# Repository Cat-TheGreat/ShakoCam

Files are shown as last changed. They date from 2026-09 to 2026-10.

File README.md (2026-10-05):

 # ShakoCam
An athletic headband with a camera. Like a GoPro, but sleeker, smaller, and much more comfortable and affordable. Designed to take POV videos during marching band performances, which is where the name comes from. My band director once said that you never really know what actually happened at the last competition of the season because the only evidence is memories, and memories tend to shift. That line was most of the inspiration for this project, and I hope it can solve the eternal dilemma.
 ## How It Works
A 1000mAh battery powers a Xiao ESP32S3, chosen for its small size but big processing power. The ESP32S3 runs its own WiFi network, which the user can connect to on their phone. They then open up a web app on their browser, which allows the user to Start/Stop recording, view SD card storage, and view recorded videos in the browser, as well as download them as MP4s to their phone. The video is recorded through an OV3660 with a 120 degree lens to capture the user's field of view. The battery can be recharged using the ESP32S3's USB. 
 ## How To Build It
 ### 1. Prepping Electronics
Follow this wiring diagram to solder the 26 AWG wire from the LiPo battery to the ESP32S3
Wires_Connections V1

Locate the camera module that comes with the ESP32S3, flip the black latch open, and remove it. Insert the longer OV3660 module.
Upload ShakoCam code onto the ESP32S3, make sure you can access the web app with your phone by connecting to ShakoCam WiFi and opening http://192.168.4.1/
 ### 2. Enclose the Electronics
3D print the battery, camera module, and ESP32S3 cases. Onshape: https://cad.onshape.com/documents/f96a4d49e3e12c14028028a5/w/6497ad0440bc11f84819475d/e/ab09dfae09777d82fe9ced0d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
Place Velcro as shown
Velcro V1

Carefully put components in their respective enclosure and make sure all pieces are secured
 ### 3. Mounting onto the headband
Cut the outer layer of the inside of the headband to get access to the inner layers
Sew matching velcro pieces onto the inside of the headband 
Attach the ESP32S3 and battery cases
Cut a hole where you want the camera lens to be, then put the camera module enclosure through and secure loose threads with adhesive
Enjoy your ShakoCam! Final product should look like this: CAD V1 Bird's View
CAD V1 Back Tilt
CAD V1 Front Tilt

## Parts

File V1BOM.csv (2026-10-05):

Item Name | Estimated Cost | Link | Total Cost
Xiao ESP32S3 Sense | $13.99 | https://www.seeedstudio.com/XIAO-ESP32S3-Sense-p-5639.html | $35.66
1000mAh 503450 LiPo Battery 3.7V | $6.41 | https://www.aliexpress.us/item/3256812637605261.html?curPageLogUid=JEKEjuLBBcFY
OV3660 Camera Module | $8.02 | https://www.aliexpress.us/item/3256812309268272.html?curPageLogUid=TWeHf9uH6LLx
26 AWG Wires | $2.26 | https://www.aliexpress.us/item/3256801954164415.html?curPageLogUid=quLryT4fYQDY
3D Printed Parts | $2.50
Black Velcro | $1.90 | https://www.aliexpress.us/item/3256805406910291.html?curPageLogUid=CvVZhRHr8c55
Black Headband | $0.58 | https://www.aliexpress.us/item/3256803432347899.html?curPageLogUid=vUSZnRrO4lS8

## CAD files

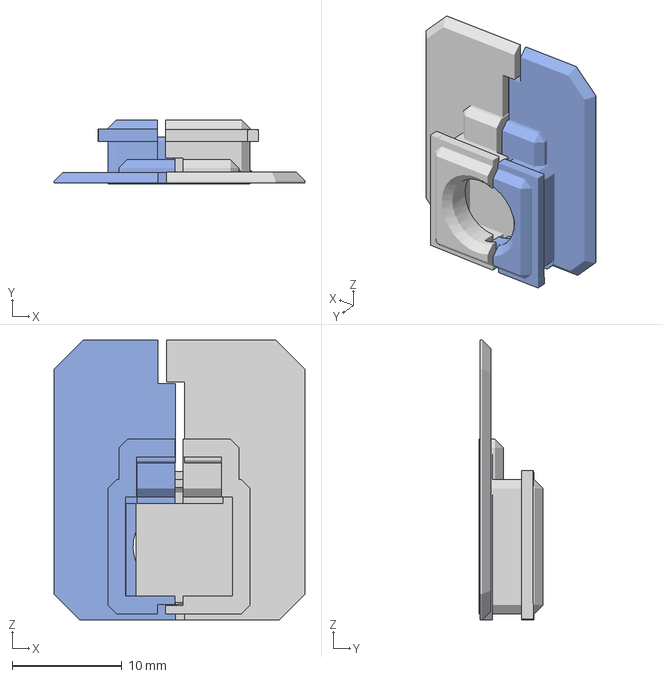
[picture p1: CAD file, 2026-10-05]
CAD/Camera Module CaseV1.step
22.8 x 5.86 x 25.5 mm

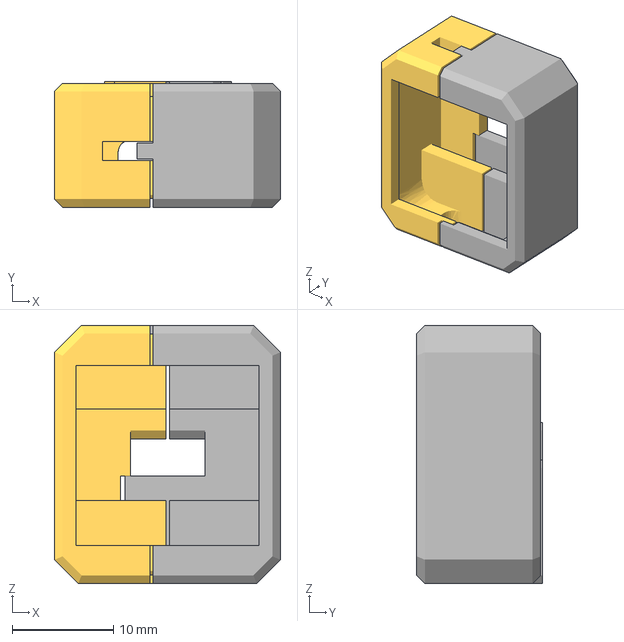
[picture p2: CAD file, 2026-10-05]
CAD/ESP32S3 Case V1.step
22.3 x 12.4 x 25.5 mm

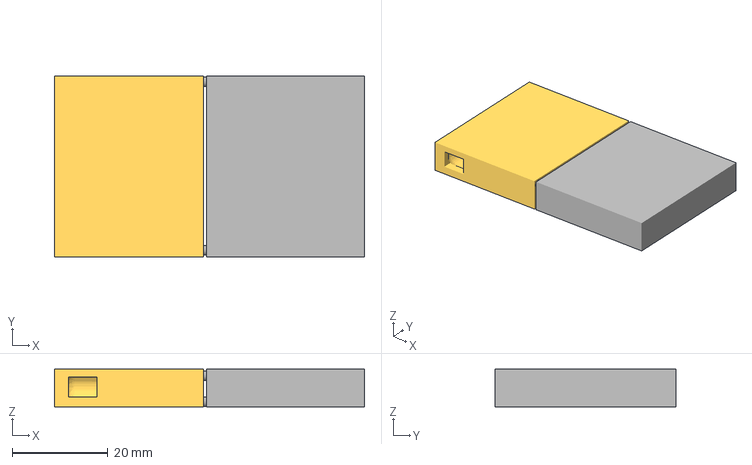
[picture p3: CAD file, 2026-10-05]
CAD/Battery Case V1.step
64.6 x 37.7 x 7.92 mm

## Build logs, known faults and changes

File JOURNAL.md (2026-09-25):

6/28/2026-Made the first initial sketch for ShakoCam, a headband with electronics concealed within it that records audio and video.
7/07/2026-After doing some research about the components, I made a list of all the components it would take for the first prototype, decided on using XIAO ESP323 and a 500mAh LiPo battery
7/21/2026-Got the first ever photo and video on my ESP32S3, used a 32GB Class 4 SanDisk microSD card that was laying around. However, the video was just one frame, so I tried to use ESP32-CAM_MJPEG2SD to actually get a proper avi recorder not like the one in the examples. Even after trying some other open source projects, they would just not work.
7/23/2026-Found another project to get a recorder up and running, but I could not succesfully convert it from ESP32 to ESP32S3(probably the Windows 7 lol), even with AI help. I switched to a different version of the same project and tried to modify that under the guidance of ChatGPT.
7/24/2026-Journaled "it feels like I'm going around in circles", used Arduino AI which did not help, after using so much AI it messed up the code, so I asked Gemini to simply write its own code from scratch. Unlike my past attempts, it successfully connected to the SD card but was having issues with taking frames. I went back to the previous code I was working on and got it to advance to a spinlock error. It was still having Sd card issues so I tried switching it from Sd_MMC to SPI but that still did not work.
7/26/2026-Still fixing the spinlock error
7/28/2026-Got frustrated with the spinlock error and simply tried using an older version of MJPEG2SD, also did not work.
7/29/2026-Once again returned to the code with the spinlock error and after switching some things around the Serial Monitor was glitching so I got frustrated and redirected my focus to the audio rather than the video. Used the SEEED Studio example to get it to record audio, and then modified it so it would start recording when it received power. Used my 5000mAh power bank to prototype and record audio. I put the whole setup in a hastily made cardboard enclosure and took it to rehearsal to see how it would withstand loud sounds.
7/30/2026-Was not able to get a recording of the band playing loud :( but it recorded the director's motivational speech just fine, however set volume gain to 0 in preparation
8/01/2026-Breakthrough Day! Feeling down since the recorder didn't even activate during rehearsal, so I went and tried getting the simplest possible video recorder going. This is when I dug around in the files of the first ever video I took, the single frame one, and found that the project I used had a folder called a decoder. Thus I did some research and through freeconverter.com I turned the one frame video into a multiple frame video! So I discovered I could just take the really simple example video recorder and put that file through a decoder and get real video. So with the help of Gemini I made a WebApp for it since the ESP32S3 has a wifi network, and I got it to control the LED with my phone which was so cool. Then, I got it to be able to press a button to my phone and save a .txt file to the SD card. Finally, I got Gemini to merge the very simple video code with the web app code to create a web app that stopped and started recording from my phone. Then, added a gallery so you can select videos and view them using the web app's decoder. Very proud.
8/02/2026-I deleted the code from the previous day by accident :( but somehow got it back? and then I worked on adding a download as .mp4 button and making it able to switch from one video, and then clicking on another video. I also tried improving the load time of the video viewer because that took a while. Successfully added the download button,also a visual to see how much storage you have left, and then I pivoted to adding audio. It did not go so well, I even accidentally deleted HandleStream in the code. I got a clip with "MEGA glitchy" audio, and in trying to fix that I broke the video recording somehow.
8/03/2026-I commented out the microphone code and the video code was back and running :), decided that the best course of action was to record a .avi and .wav simultaneously and then combine them in the web app. After hacking away at it, I got 7 seconds of crappy audio for 38 seconds of video, however my speech was audible. I added a mutex-not sure for what? Using a stopwatch I timed the length of the video, turns out it was playing way too slow for the frames it took. Using the combined powers of ChatGPT and Gemini a clock was implemented to sync them, which somehow cleared up the audio quality as well. It worked like a camera which I was very proud of. However this broke the download button because codec was not read, I got it to download but my phone displayed that it was 6 seconds long but it played the 1min and 16sec long video which was odd.
8/04/2026-Big Mistake Day: We were doing a part of our show that we had never done before and I really wanted to film it, and I thought with all this progress that it was ready, so I tried putting the battery pack and the ESP32S3 onto a baseball cap. This concluded in me using a tic tac box to house the ESP32S3. Bad mistake. I think this broke the ribbon cable, which broke the camera module. It was not able to record video after this :(
8/05/2026-Trying to confirm that the camera module was broken, I somehow corrupted the SD card and spent my time researching how to and recovering the SD card.
8/06/2026-Did not successfully recover the videos, but even after plugging in the fresh SD card the camera still couldn't even take simple photos it was just all black, so I reached out to customer support to see if they would replace it.
8/16/2026-Customer support did in fact send a replacement ESP32S3 yay! So learning from my mistakes I measured the dimensions of the ESP32S3 and designed a blocky enclosure in TinkerCad
8/26/2026-The replacement ESP32S3 arrived from Seeed on this day
8/29/2026-After unboxing the XIAO I plugged into the beautiful Windows 7 and it said it was printer. So, I plug in the old one and it says it is also a printer. Wow! I messed around for a bit with the drivers and I got Arduino to recognize it. I sent my expertly designed case to the school library to get printed, and got notified that the 3d printer was broken. I got the new ESP32S3 to run CameraWebServer! In a tragic turn of events, I tried disconnecting the Wifi antennae and accidentally took the whole connector with it so I discreetly swapped boards with the old one. CameraWebServer executed perfectly and when I upload the ShakoCam code and test the audio while I play my instrument the audio pops. Therefore, I lower volume gain and adjust the clock speed.
9/07/2026-On this day I realize I can just get a masterfully designed case from the internet instead of designing it myself. I send this to the library. I begin contemplating the battery because that's the bulkiest part at this point.
9/14/2026-I finally get the 3d print! I take out all the supports and it fits perfectly. However, is it a lot bulkier than I imagined and might not sleekly go into a headband. I also ordered a 1000mAh LiPo battery which might be a little overkill but better safe than sorry. With the case, I can now start testing.
9/16/2026-I put the power bank and the ESP32S3 in my fanny pack and take it out the rehearsal! It survived the ruthless heat and loud conversations, although I couldn't connect it fast enough to get a video of the band actually playing. I made a note that the video is really low quality.
9/17/2026-I get some really good videos 20-30 min long of our rehearsal, the first time I record our whole band. However the camera was aimed at the inside of the fanny pack and I did not get to analyze the videos much because I was busy, but it handled itself pretty well + had some mic popping and timing issues here and there 
9/25/2026-Tragedy strikes. It's been a week since the fanny pack was lost, with all the components in it :(. I research funding options to replace all that I have lost because I've spent a lot already, and I found HackClub. I started this GitHub repository and paraphrased everything from my journal. Also, someone between this and 9/17 I took apart an old Joy-Con to see if any parts could be salvaged and I realized how big soldering will be in this project, which I have 0 experience with. I also confirmed that the old ESP32S3 still works, just doesn't have an SD card or a functioning camera module.

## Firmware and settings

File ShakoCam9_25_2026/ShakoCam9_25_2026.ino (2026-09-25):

#include "esp_camera.h"
#include "FS.h"
#include "SD.h"
#include "SPI.h"
#include "esp_timer.h"
#include <WiFi.h>
#include <WebServer.h>
#include "driver/i2s.h"

// Microphone Pin & Channel Definitions
#define I2S_MIC_CLK     42
#define I2S_MIC_DATA    41
#define SAMPLE_RATE     16000U
#define SAMPLE_BITS     16

#define CAMERA_MODEL_XIAO_ESP32S3
#include "camera_pins.h"

const char* ssid = "ShakoCam";
const char* password = "password123";
WebServer server(80);

SemaphoreHandle_t sdMutex;
TaskHandle_t audioTaskHandle = NULL;

const int SD_PIN_CS = 21;

// Separate File Handles for Video and Audio
File videoFile;
File audioFile;

bool camera_sign = false;
bool sd_sign = false;
volatile bool isRecording = false;

char currentFilename[32];  // e.g. /video0.avi
char audioFilename[32];    // e.g. /audio0.wav

int frameCount = 0;
uint32_t audioBytesWritten = 0;

// Helper function to write a standard 44-byte WAV Header
void writeWavHeader(File file, uint32_t sampleRate, uint16_t bitsPerSample, uint16_t channels) {
  uint8_t header[44];
  
  // "RIFF" chunk descriptor
  header[0] = 'R'; header[1] = 'I'; header[2] = 'F'; header[3] = 'F';
  uint32_t fileSize = 0; // Temporary placeholder
  memcpy(&header[4], &fileSize, 4);
  header[8] = 'W'; header[9] = 'A'; header[10] = 'V'; header[11] = 'E';

  // "fmt " sub-chunk
  header[12] = 'f'; header[13] = 'm'; header[14] = 't'; header[15] = ' ';
  uint32_t subchunk1Size = 16; // PCM format
  memcpy(&header[16], &subchunk1Size, 4);
  uint16_t audioFormat = 1;   // Uncompressed PCM
  memcpy(&header[20], &audioFormat, 2);
  memcpy(&header[22], &channels, 2);
  memcpy(&header[24], &sampleRate, 4);
  
  uint32_t byteRate = sampleRate * channels * (bitsPerSample / 8);
  memcpy(&header[28], &byteRate, 4);
  uint16_t blockAlign = channels * (bitsPerSample / 8);
  memcpy(&header[32], &blockAlign, 2);
  memcpy(&header[34], &bitsPerSample, 2);

  // "data" sub-chunk
  header[36] = 'd'; header[37] = 'a'; header[38] = 't'; header[39] = 'a';
  uint32_t dataSize = 0; // Temporary placeholder
  memcpy(&header[40], &dataSize, 4);

  file.write(header, 44);
}

void initMicrophone() {
  i2s_config_t i2s_config = {
    .mode = (i2s_mode_t)(I2S_MODE_MASTER | I2S_MODE_RX | I2S_MODE_PDM),
    .sample_rate = 16000,
    .bits_per_sample = I2S_BITS_PER_SAMPLE_16BIT,
    .channel_format = I2S_CHANNEL_FMT_ONLY_LEFT,
    .communication_format = I2S_COMM_FORMAT_STAND_I2S,
    .intr_alloc_flags = ESP_INTR_FLAG_LEVEL1,
    .dma_buf_count = 4,
    .dma_buf_len = 512,
    .use_apll = false,
    .tx_desc_auto_clear = false,
    .fixed_mclk = 0
  };

  i2s_pin_config_t pin_config = {
    .bck_io_num = I2S_PIN_NO_CHANGE,
    .ws_io_num = I2S_MIC_CLK,
    .data_out_num = I2S_PIN_NO_CHANGE,
    .data_in_num = I2S_MIC_DATA
  };

  esp_err_t err = i2s_driver_install(I2S_NUM_0, &i2s_config, 0, NULL);
  if (err != ESP_OK) {
    Serial.printf("I2S driver install failed: %d\n", err);
    return;
  }

  err = i2s_set_pin(I2S_NUM_0, &pin_config);
  if (err != ESP_OK) {
    Serial.printf("I2S pin setup failed: %d\n", err);
    return;
  }

  i2s_start(I2S_NUM_0);
  Serial.println("Lightweight PDM Microphone Initialized!");
}

const char INDEX_HTML[] PROGMEM = R"rawliteral(
<!DOCTYPE html>
<html>
<head>
  <meta name="viewport" content="width=device-width, initial-scale=1">
  <style>
    body { font-family: Arial, sans-serif; text-align: center; background: #121212; color: white; padding: 15px; margin: 0; }
    .btn { padding: 12px 24px; font-size: 16px; border: none; border-radius: 8px; margin: 5px; cursor: pointer; font-weight: bold; }
    .rec { background-color: #e50914; color: white; }
    .stop { background-color: #555555; color: white; }
    .save { background-color: #28a745; color: white; width: 100%; max-width: 320px; }
    .refresh { background-color: #007aff; color: white; padding: 6px 12px; font-size: 14px; border-radius: 5px; border: none; }
    #status { margin: 10px; font-size: 15px; color: #00ffcc; }
    
    #storageBox { background: #1e1e1e; padding: 12px; border-radius: 8px; margin: 15px auto; max-width: 400px; text-align: left; }
    .bar-bg { background: #333; height: 12px; border-radius: 6px; overflow: hidden; margin-top: 6px; }
    .bar-fill { background: #00ffcc; height: 100%; width: 0%; transition: width 0.4s ease; }

    #playerContainer { display: none; margin: 15px auto; max-width: 400px; background: #1e1e1e; padding: 15px; border-radius: 10px; }
    #canvasDisplay { width: 100%; height: auto; border-radius: 6px; background: #000; }
    
    #gallery { margin-top: 20px; text-align: left; background: #1e1e1e; padding: 15px; border-radius: 10px; max-width: 400px; margin-left: auto; margin-right: auto; }
    .file-item { display: flex; justify-content: space-between; align-items: center; padding: 10px 0; border-bottom: 1px solid #333; }
    .file-info { display: flex; flex-direction: column; }
    .file-meta { font-size: 12px; color: #aaa; margin-top: 3px; }
    .play-btn { background: #007aff; color: white; border: none; padding: 8px 12px; border-radius: 6px; cursor: pointer; font-weight: bold; }
  </style>
</head>
<body>
  <h2>ShakoCam</h2>
  <button class="btn rec" onclick="startRec()">RECORD</button>
  <button class="btn stop" onclick="stopRec()">STOP</button>
  <div id="status">Status: Ready</div>

  <div id="storageBox">
    <div style="display:flex; justify-content:space-between; font-size:13px;">
      <span>SD Card Storage</span>
      <span id="storageText">Loading...</span>
    </div>
    <div class="bar-bg">
      <div id="storageBar" class="bar-fill"></div>
    </div>
  </div>

  <div id="playerContainer">
    <h4 id="nowPlaying" style="margin: 5px 0 10px 0;">Video Player</h4>
    <canvas id="canvasDisplay"></canvas>
    <audio id="audioPlayer" controls style="width: 100%; margin-top: 10px; display: none;"></audio>
    <br><br>
    <button class="btn save" id="dlBtn" onclick="saveAsMP4()">Save to Phone</button>
  </div>

  <div id="gallery">
    <div style="display: flex; justify-content: space-between; align-items: center;">
      <h3 style="margin:0;">Saved Clips</h3>
      <button class="refresh" onclick="loadGallery()">Refresh</button>
    </div>
    <div id="fileList" style="margin-top: 10px;">Loading files...</div>
  </div>

  <script>
    let playAnimationId = null;
    let extractedFrames = [];
    let isPlaying = false;
    let activeFilename = "";

    function startRec() {
      fetch('/start');
      document.getElementById('status').innerText = "Status: Recording Video & Audio...";
    }
    
    function stopRec() {
      fetch('/stop');
      document.getElementById('status').innerText = "Status: Stopped & Saved!";
      setTimeout(() => { loadGallery(); loadStorage(); }, 1000);
    }
    
    function loadStorage() {
      fetch('/storage').then(r => r.json()).then(data => {
        const freeMB = data.total - data.used;
        const usedPct = ((data.used / data.total) * 100).toFixed(1);
        document.getElementById('storageText').innerText = (freeMB/1024).toFixed(1) + " GB free of " + (data.total/1024).toFixed(1) + " GB";
        document.getElementById('storageBar').style.width = usedPct + '%';
      }).catch(err => {
        document.getElementById('storageText').innerText = "Unavailable";
      });
    }

    function loadGallery() {
      fetch('/list')
        .then(r => r.json())
        .then(files => {
          let html = '';
          if (!files || files.length === 0) {
            html = '<p>No recordings found.</p>';
          } else {
            files.forEach(f => {
              const sizeMB = (f.size / (1024 * 1024)).toFixed(1);
              html += '<div class="file-item">' +
                '<div class="file-info">' +
                  '<strong>' + f.name + '</strong>' +
                  '<span class="file-meta">Size: ' + sizeMB + ' MB</span>' +
                '</div>' +
                '<button class="play-btn" onclick="playVideo(\'' + f.name + '\')">PLAY</button>' +
              '</div>';
            });
          }
          document.getElementById('fileList').innerHTML = html;
        })
        .catch(err => {
          document.getElementById('fileList').innerHTML = '<p>Error loading list</p>';
        });
    }

    function stopCurrentPlayback() {
      isPlaying = false;
      if (playAnimationId) cancelAnimationFrame(playAnimationId);
      const audioElem = document.getElementById('audioPlayer');
      audioElem.pause();
      audioElem.src = "";
      extractedFrames = [];
    }

    async function playVideo(filename) {
      stopCurrentPlayback();
      activeFilename = filename;

      const playerContainer = document.getElementById('playerContainer');
      const nowPlaying = document.getElementById('nowPlaying');
      const audioElem = document.getElementById('audioPlayer');
      
      playerContainer.style.display = 'block';
      nowPlaying.innerText = "Downloading " + filename + "...";

      try {
        const response = await fetch('/stream?file=' + filename);
        if (!response.ok) throw new Error("Fetch video failed");
        
        nowPlaying.innerText = "Extracting video frames...";
        const arrayBuffer = await response.arrayBuffer();
        const bytes = new Uint8Array(arrayBuffer);
        let i = 0;

        while (i < bytes.length - 1) {
          if (bytes[i] === 0xFF && bytes[i+1] === 0xD8) {
            let start = i;
            i += 2;
            while (i < bytes.length - 1) {
              if (bytes[i] === 0xFF && bytes[i+1] === 0xD9) {
                i += 2;
                extractedFrames.push(bytes.subarray(start, i));
                break;
              }
              i++;
            }
          } else {
            i++;
          }
        }

        if (extractedFrames.length === 0) {
          nowPlaying.innerText = "No video frames found";
          return;
        }

        const audioName = filename.replace("video", "audio").replace(".avi", ".wav");
        audioElem.src = '/stream?file=' + audioName;
        audioElem.style.display = 'block';
        audioElem.load();

        nowPlaying.innerText = "Playing: " + filename;
        isPlaying = true;

        audioElem.onplay = () => { isPlaying = true; syncLoop(); };
        audioElem.onpause = () => { isPlaying = false; };
        audioElem.onended = () => { isPlaying = false; };
        audioElem.onseeking = () => { renderFrameAtAudioClock(); };

        audioElem.play().catch(e => console.log("Audio play interaction required"));

      } catch (err) {
        nowPlaying.innerText = "Error loading clip";
      }
    }

    function syncLoop() {
      if (!isPlaying) return;
      renderFrameAtAudioClock();
      playAnimationId = requestAnimationFrame(syncLoop);
    }

    function renderFrameAtAudioClock() {
      const audioElem = document.getElementById('audioPlayer');
      if (!audioElem.duration || extractedFrames.length === 0) return;

      const progress = audioElem.currentTime / audioElem.duration;
      const frameIndex = Math.min(
        Math.floor(progress * extractedFrames.length),
        extractedFrames.length - 1
      );

      const canvas = document.getElementById('canvasDisplay');
      const ctx = canvas.getContext('2d');
      const frameData = extractedFrames[frameIndex];

      if (!frameData) return;

      const blob = new Blob([frameData], { type: 'image/jpeg' });
      const url = URL.createObjectURL(blob);
      const img = new Image();

      img.onload = () => {
        canvas.width = img.width || 640;
        canvas.height = img.height || 480;
        ctx.drawImage(img, 0, 0);
        URL.revokeObjectURL(url);
      };
      img.src = url;
    }

    async function saveAsMP4() {
      if (extractedFrames.length === 0) return;

      const canvas = document.getElementById('canvasDisplay');
      const audioElem = document.getElementById('audioPlayer');
      const dlBtn = document.getElementById('dlBtn');

      dlBtn.innerText = "Exporting Video...";
      dlBtn.disabled = true;

      const canvasStream = canvas.captureStream(15);
      
      const audioCtx = new (window.AudioContext || window.webkitAudioContext)();
      const audioSource = audioCtx.createMediaElementSource(audioElem);
      const audioDest = audioCtx.createMediaStreamDestination();
      
      audioSource.connect(audioCtx.destination);
      audioSource.connect(audioDest);

      const combinedStream = new MediaStream([
        ...canvasStream.getVideoTracks(),
        ...audioDest.stream.getAudioTracks()
      ]);

      const types = [
        'video/mp4;codecs=avc1.42E01E,mp4a.40.2',
        'video/mp4;codecs=h264,aac',
        'video/mp4',
        'video/webm;codecs=vp8,opus',
        'video/webm'
      ];

      let selectedMime = '';
      for (let t of types) {
        if (MediaRecorder.isTypeSupported(t)) {
          selectedMime = t;
          break;
        }
      }

      if (!selectedMime) {
        alert("MediaRecorder is not supported on this browser.");
        dlBtn.innerText = "Save to Phone";
        dlBtn.disabled = false;
        return;
      }

      const recorder = new MediaRecorder(combinedStream, { 
        mimeType: selectedMime,
        audioBitsPerSecond: 128000
      });

      const chunks = [];

      recorder.ondataavailable = (e) => { 
        if (e.data && e.data.size > 0) chunks.push(e.data); 
      };
      
      recorder.onstop = () => {
        const blob = new Blob(chunks, { type: selectedMime });
        const url = URL.createObjectURL(blob);
        const a = document.createElement('a');
        a.href = url;
        
        const isMp4 = selectedMime.includes('mp4');
        const ext = isMp4 ? '.mp4' : '.webm';
        a.download = activeFilename.replace('.avi', ext);
        
        document.body.appendChild(a);
        a.click();
        document.body.removeChild(a);
        URL.revokeObjectURL(url);

        dlBtn.innerText = "Downloaded!";
        dlBtn.disabled = false;
        setTimeout(() => { dlBtn.innerText = "Save to Phone"; }, 3000);
      };

      audioElem.currentTime = 0;
      await audioElem.play();
      recorder.start(100);

      audioElem.onended = () => {
        recorder.stop();
        audioCtx.close();
      };
    }
    
    window.onload = () => {
      loadGallery();
      loadStorage();
    };
  </script>
</body>
</html>
)rawliteral";

void handleRoot() {
  server.send(200, "text/html", INDEX_HTML);
}

void audioTask(void *pvParameters) {
  uint8_t audioBuffer[512];
  size_t bytesRead = 0;

  for (;;) {
    if (isRecording) {
      i2s_read(I2S_NUM_0, audioBuffer, sizeof(audioBuffer), &bytesRead, pdMS_TO_TICKS(10));

      if (bytesRead > 0) {
        // --- HIGH VOLUME ATTENUATION FOR BRASS (DIVIDE BY 4) ---
        int16_t *samples = (int16_t *)audioBuffer;
        size_t sampleCount = bytesRead / 2;
        for (size_t i = 0; i < sampleCount; i++) {
          samples[i] = samples[i] / 4; 
        }

        // Non-blocking SD write with a 10ms timeout
        if (xSemaphoreTake(sdMutex, pdMS_TO_TICKS(10)) == pdTRUE) {
          if (audioFile) {
            audioFile.write(audioBuffer, bytesRead);
            audioBytesWritten += bytesRead;
          }
          xSemaphoreGive(sdMutex);
        }
      }
    } else {
      vTaskDelay(pdMS_TO_TICKS(20));
    }
  }
}

void handleStart() {
  if (!camera_sign || !sd_sign) {
    server.send(500, "text/plain", "Hardware Error");
    return;
  }

  if (!isRecording) {
    // Flush 10 dummy frames to completely warm up the OV3660 camera DMA pipeline
    for (int i = 0; i < 10; i++) {
      camera_fb_t *dummy = esp_camera_fb_get();
      if (dummy) esp_camera_fb_return(dummy);
      vTaskDelay(pdMS_TO_TICKS(15));
    }

    if (videoFile) videoFile.close();
    if (audioFile) audioFile.close();

    int fileNumber = 0;
    while (true) {
      sprintf(currentFilename, "/video%d.avi", fileNumber);
      sprintf(audioFilename, "/audio%d.wav", fileNumber);
      if (!SD.exists(currentFilename) && !SD.exists(audioFilename)) break;
      fileNumber++;
    }

    videoFile = SD.open(currentFilename, FILE_WRITE);
    audioFile = SD.open(audioFilename, FILE_WRITE);

    if (videoFile && audioFile) {
      writeWavHeader(audioFile, 16000, 16, 1);
      audioBytesWritten = 0;

      isRecording = true;
      frameCount = 0;
      Serial.printf("\n--- [PHONE] Started Recording: %s & %s ---\n", currentFilename, audioFilename);
    }
  }
  server.send(200, "text/plain", "RECORDING");
}

void handleStop() {
  if (isRecording) {
    isRecording = false;

    if (xSemaphoreTake(sdMutex, pdMS_TO_TICKS(500)) == pdTRUE) {
      if (videoFile) {
        videoFile.flush();
        videoFile.close();
      }

      if (audioFile) {
        uint32_t totalFileSize = audioBytesWritten + 36;
        audioFile.seek(4);
        audioFile.write((uint8_t*)&totalFileSize, 4);

        audioFile.seek(40);
        audioFile.write((uint8_t*)&audioBytesWritten, 4);

        audioFile.flush();
        audioFile.close();
      }

      xSemaphoreGive(sdMutex);
    }

    Serial.printf(
      "--- [PHONE] Stopped! Saved %d frames (%s) & %d audio bytes (%s) ---\n\n",
      frameCount, currentFilename, audioBytesWritten, audioFilename
    );
  }

  server.send(200, "text/plain", "STOPPED");
}

void handleStorage() {
  uint64_t totalBytes = SD.totalBytes();
  uint64_t usedBytes = SD.usedBytes();
  
  String json = "{";
  json += "\"total\":" + String((unsigned long)(totalBytes / (1024 * 1024))) + ",";
  json += "\"used\":" + String((unsigned long)(usedBytes / (1024 * 1024)));
  json += "}";
  
  server.send(200, "application/json", json);
}

void handleStream() {
  if (!server.hasArg("file")) {
    server.send(400, "text/plain", "Missing file parameter");
    return;
  }

  String fileName = server.arg("file");
  if (!fileName.startsWith("/")) {
    fileName = "/" + fileName;
  }

  File streamFile = SD.open(fileName, FILE_READ);
  if (!streamFile) {
    server.send(404, "text/plain", "File not found");
    return;
  }

  String dataType = "application/octet-stream";
  if (fileName.endsWith(".wav")) {
    dataType = "audio/wav";
  } else if (fileName.endsWith(".avi")) {
    dataType = "video/x-motion-jpeg";
  }

  server.setContentLength(streamFile.size());
  server.send(200, dataType, "");

  WiFiClient client = server.client();
  uint8_t buffer[1024];

  while (streamFile.available()) {
    int bytesRead = streamFile.read(buffer, sizeof(buffer));
    client.write(buffer, bytesRead);
  }

  streamFile.close();
}

void handleList() {
  File root = SD.open("/");
  if (!root) {
    server.send(500, "application/json", "[]");
    return;
  }

  String json = "[";
  File file = root.openNextFile();
  bool first = true;

  while (file) {
    String fileName = String(file.name());
    if (fileName.startsWith("/")) {
      fileName = fileName.substring(1);
    }

    if (!file.isDirectory() && fileName.endsWith(".avi")) {
      if (!first) json += ",";
      json += "{\"name\":\"" + fileName + "\",\"size\":" + String(file.size()) + "}";
      first = false;
    }
    file = root.openNextFile();
  }
  json += "]";
  root.close();
  
  server.send(200, "application/json", json);
}
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
void loop() {
  server.handleClient();

  if (isRecording) {
    camera_fb_t *fb = esp_camera_fb_get();
    
    if (fb) {
      // Non-blocking SD write with a 10ms timeout
      if (xSemaphoreTake(sdMutex, pdMS_TO_TICKS(10)) == pdTRUE) {
        if (videoFile) {
          videoFile.write(fb->buf, fb->len);
          frameCount++;
        }
        xSemaphoreGive(sdMutex);
      }
      esp_camera_fb_return(fb);
    }

    if (frameCount % 30 == 0) {
      if (xSemaphoreTake(sdMutex, pdMS_TO_TICKS(10)) == pdTRUE) {
        if (videoFile) videoFile.flush();
        if (audioFile) audioFile.flush();
        xSemaphoreGive(sdMutex);
      }
    }

    vTaskDelay(pdMS_TO_TICKS(20)); // Targets ~15 FPS capture rate
  }
}

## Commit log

2026-09-25 Added current code
2026-09-25 Update README with current project components
    Added a brief description of the current components used in the project.
2026-10-05 Uploaded V1BOM
    Added the BOM for V1, with links and total cost
    [V1BOM.csv]
2026-10-05 Created CAD folder
2026-10-05 Added CAD files to CAD folder
    [Battery Case V1.step, Camera Module CaseV1.step, ESP32S3 Case V1.step]
2026-10-11 Create CAD folder
2026-10-11 Rename Battery Case V1 (1).step to Battery Case V1.step
